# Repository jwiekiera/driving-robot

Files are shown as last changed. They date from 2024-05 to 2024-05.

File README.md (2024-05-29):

# Driving Robot

Project description: The project aims to create a mobile robot. The device can overcome obstacles detected by sensors (e.g., walls, objects on the ground). The robot moves using mechanical wheels.

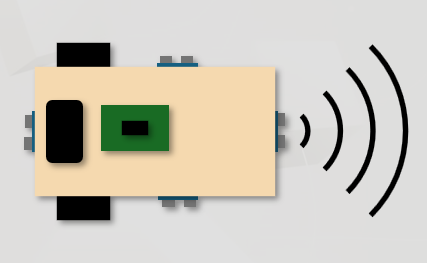
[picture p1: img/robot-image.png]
Robot image


* (20.10.2023) **Version 0.1**: Project work initiation
* (20.12.2023) **Version 0.2:** Placement of components on the platform
* (27.12.2023) **Version 0.3:** Completion of project implementation on the breadboard
* (09.02.2024) **Version 0.4:** Soldering the components together
* (13.02.2024) **Version 1.0:** Final version of the project

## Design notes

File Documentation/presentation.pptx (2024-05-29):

## Robot jeżdżący

Joanna Wiekiera

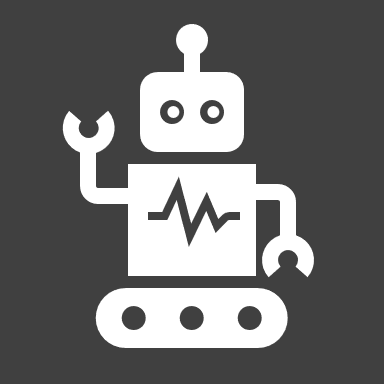
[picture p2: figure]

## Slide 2

Założenia

Robot jeżdżący, potrafiący omijać napotkane przeszkody

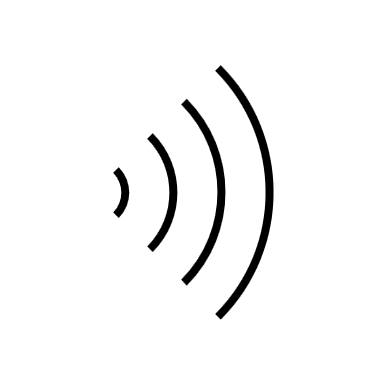
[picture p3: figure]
Wi-Fi outline

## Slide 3

Założenia

Robot jeżdżący, potrafiący omijać napotkane przeszkody

!

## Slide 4

Założenia

Robot jeżdżący, potrafiący omijać napotkane przeszkody

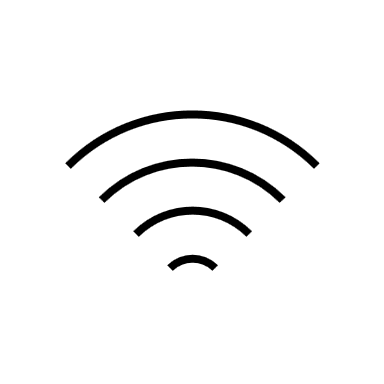
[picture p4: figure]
Wi-Fi outline

?

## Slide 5

Założenia

Robot jeżdżący, potrafiący omijać napotkane przeszkody

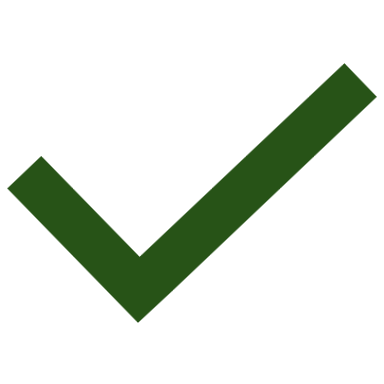
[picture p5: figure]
Checkmark with solid fill

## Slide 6

Założenia

Robot jeżdżący, potrafiący omijać napotkane przeszkody

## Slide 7

Założenia

Plany na rozwój: zaimplementowanie algorytmu parkowania równoległego

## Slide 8

Założenia

Plany na rozwój: zaimplementowanie algorytmu parkowania równoległego

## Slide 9

Założenia

Plany na rozwój: zaimplementowanie algorytmu parkowania równoległego

?

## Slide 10

Założenia

Plany na rozwój: zaimplementowanie algorytmu parkowania równoległego

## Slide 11

Założenia

Plany na rozwój: zaimplementowanie algorytmu parkowania równoległego

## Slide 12

Założenia

Plany na rozwój: zaimplementowanie algorytmu parkowania równoległego

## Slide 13

Założenia

Plany na rozwój: zaimplementowanie algorytmu parkowania równoległego

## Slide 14

Założenia

Plany na rozwój: zaimplementowanie algorytmu parkowania równoległego

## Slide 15

Elementy

- moduł Arduino Uno Rev3 z mikrokontrolerem AVR ATmega328
- cztery czujniki ultradźwiękowe HC-SR04
- robot wyposażony w trzy kółka – dwa tylnie wyposażone w silniki i przednie nienapędzane
- sterowanie tylnymi kołami kontrolowane dwukanałowym sterownikiem silników L293D

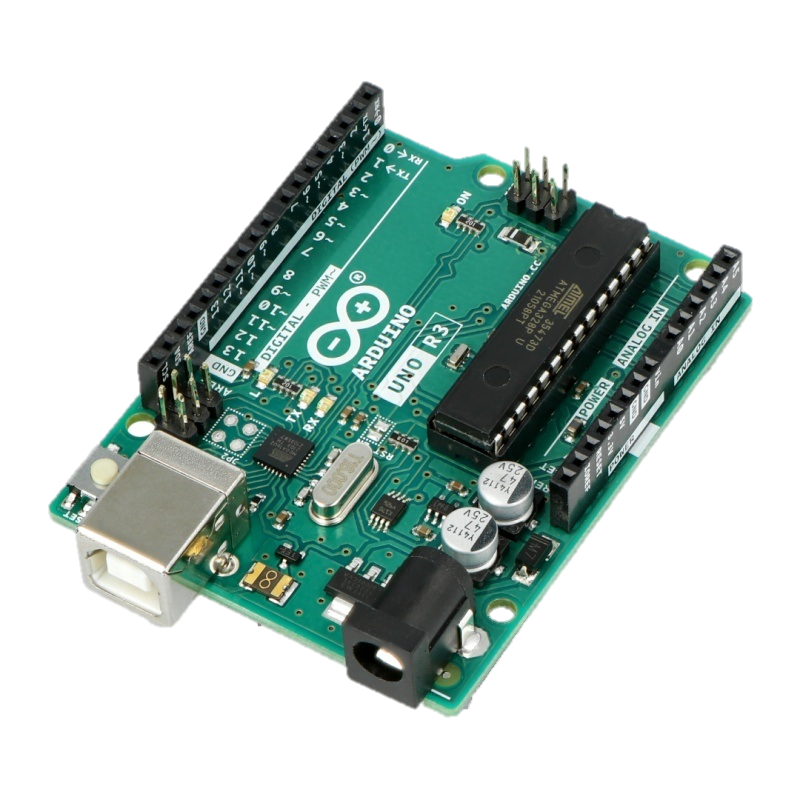
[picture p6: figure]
Arduino Uno Rev3 - A000066 Sklep Botland
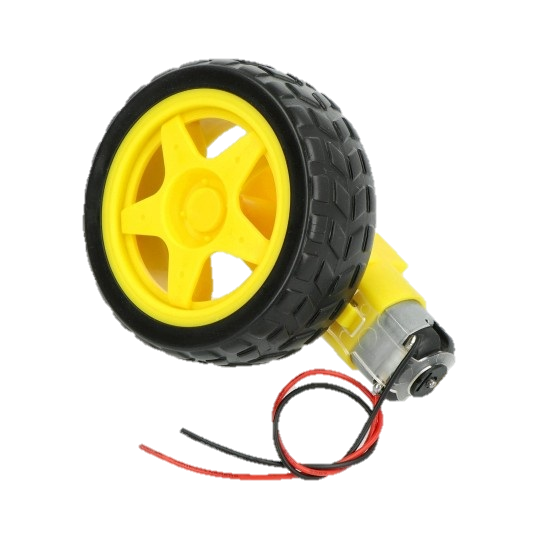
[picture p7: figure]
Koło + silnik 65x26mm 5V z przekładnią 48:1 + przewody
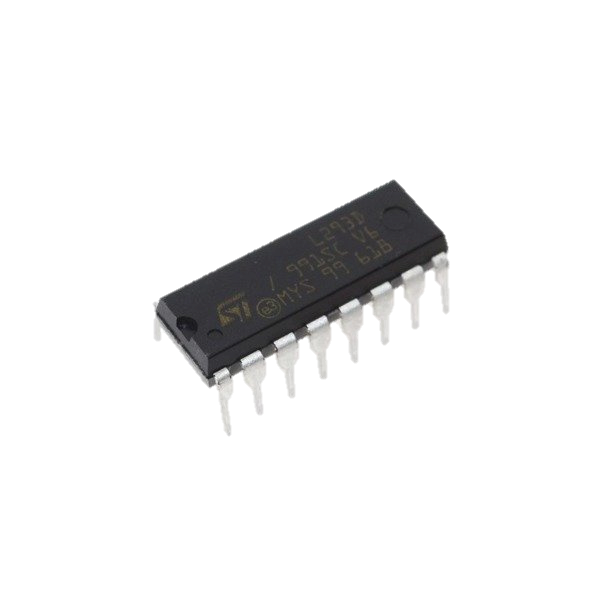
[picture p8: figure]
Układ scalony L293D - Sterownik silnika 2x Mostek H - DIP-16 L293
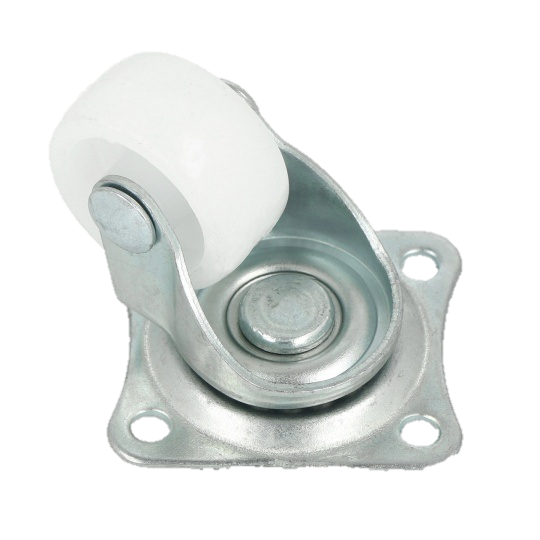
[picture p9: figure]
Obrotowe kółko do podwozia robota

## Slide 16

HC-SR04

Czujnik wysyła sygnał ultradźwiękowy, a następnie czeka na jego powrót po odbiciu od przeszkody. Odległość obliczana jest ze wzoru:

L=T∙340/2

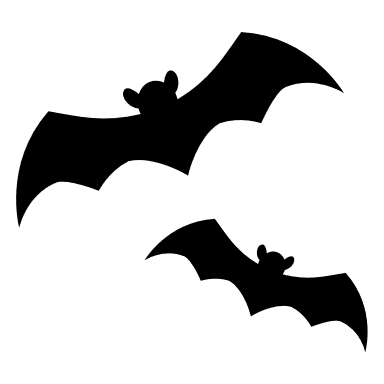
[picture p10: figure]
Bats with solid fill
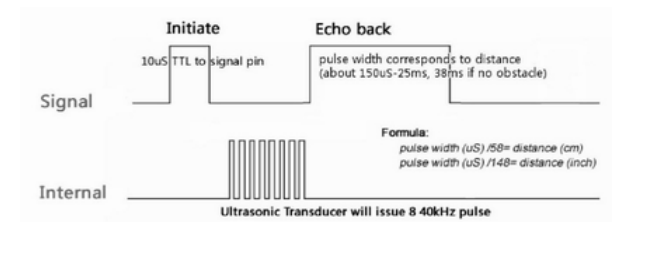
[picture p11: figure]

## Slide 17

HC-SR04

Czujnik wysyła sygnał ultradźwiękowy, a następnie czeka na jego powrót po odbiciu od przeszkody. Odległość obliczana jest ze wzoru:

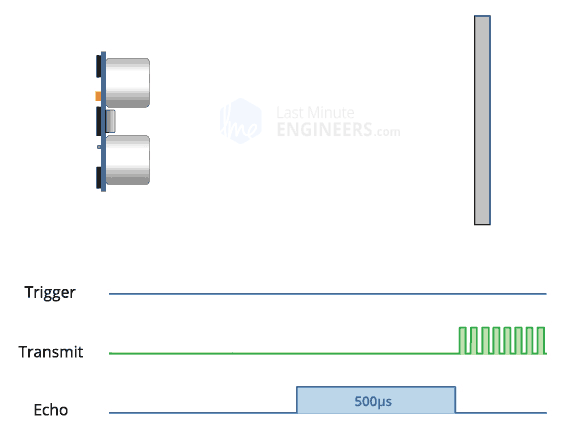
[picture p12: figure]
How HC-SR04 Ultrasonic Sensor Works & How to Interface It With Arduino

L=T∙340/2

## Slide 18

HC-SR04

L [m] – odległość
T [s] – czas od wysłania sygnału do jego powrotu
340 m/s – prędkość dźwięku w powietrzu
2 – uwzględnienie czasu w tylko w jedną stronę

Czujnik wysyła sygnał ultradźwiękowy, a następnie czeka na jego powrót po odbiciu od przeszkody. Odległość obliczana jest ze wzoru:

L=T∙340/2

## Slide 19

HC-SR04

L [cm] – odległość
T [μs] – czas od wysłania sygnału do jego powrotu

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

L=T /58

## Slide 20

L293D

Dwukanałowy sterownik silników DC (mostek H), sterujący kierunkiem kręcenia się kół poprzez zmianę biegunów zasilania

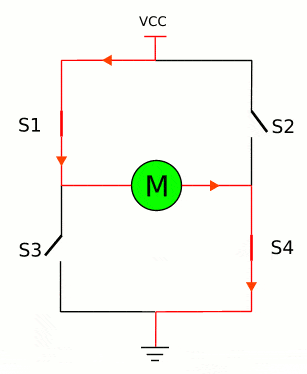
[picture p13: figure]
Teoria] Mostek H (H-bridge) - kompendium dla robotyka - Artykuły użytkowników - FORBOT

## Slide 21

L293D

Dwukanałowy sterownik silników DC (mostek H), sterujący kierunkiem kręcenia się kół poprzez zmianę biegunów zasilania

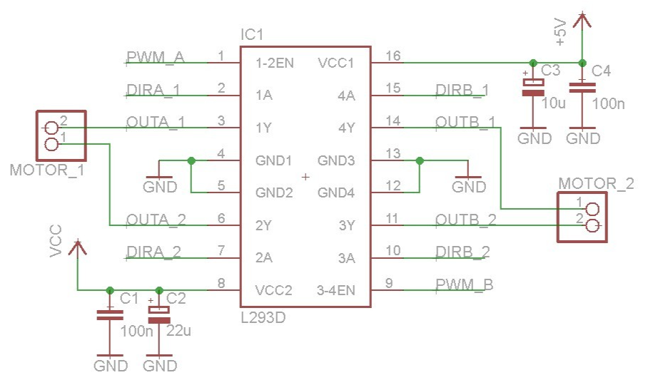
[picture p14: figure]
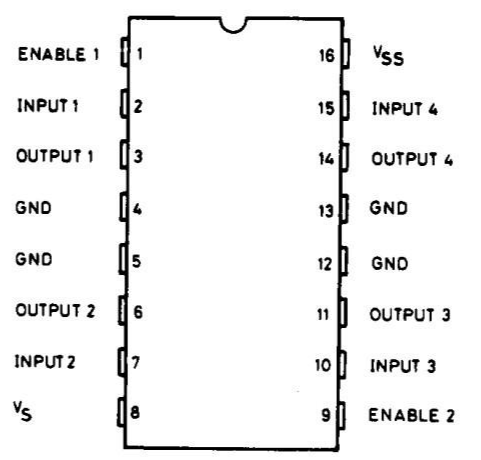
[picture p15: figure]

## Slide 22

Zasilanie

Zasilanie sześcioma bateriami AA (1,5V) połączonych szeregowo (co daje 9V).

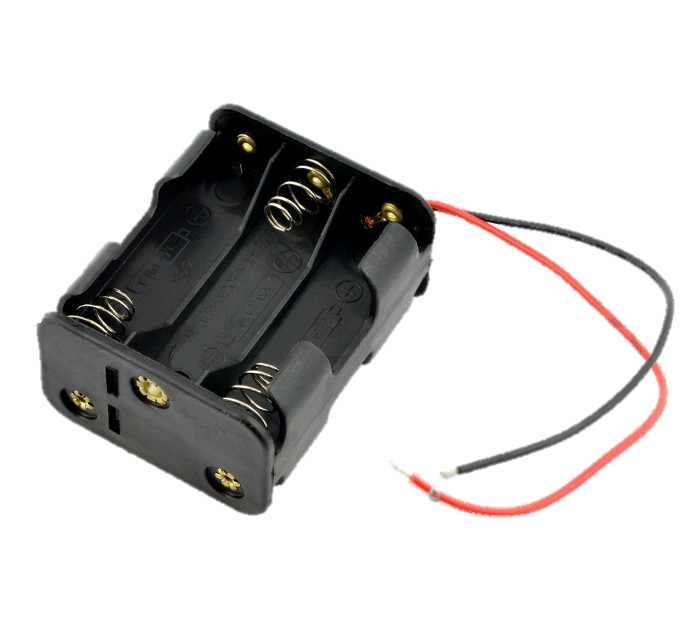
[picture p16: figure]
Slide
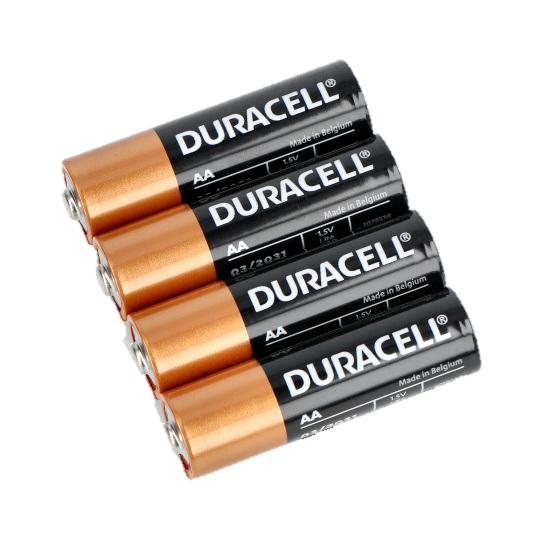
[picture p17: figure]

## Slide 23

Schemat
blokowy

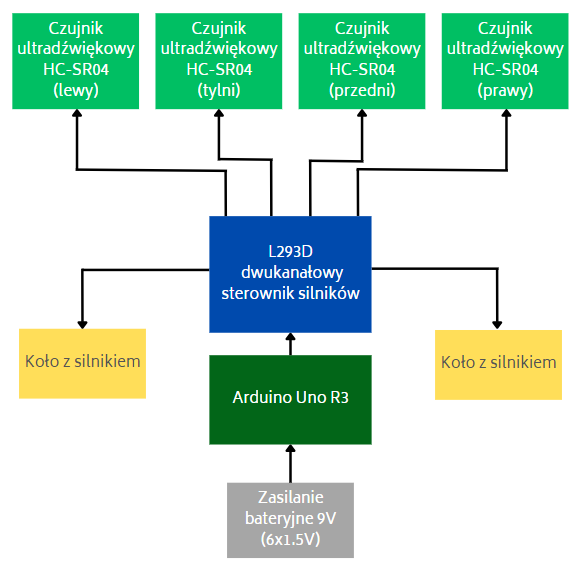
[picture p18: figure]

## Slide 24

Schemat
ideowy

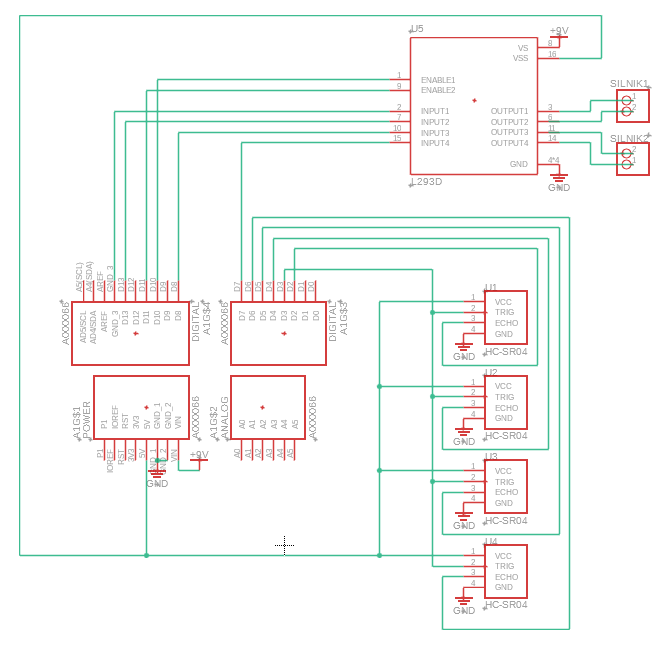
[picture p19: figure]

## Dziękuję za uwagę

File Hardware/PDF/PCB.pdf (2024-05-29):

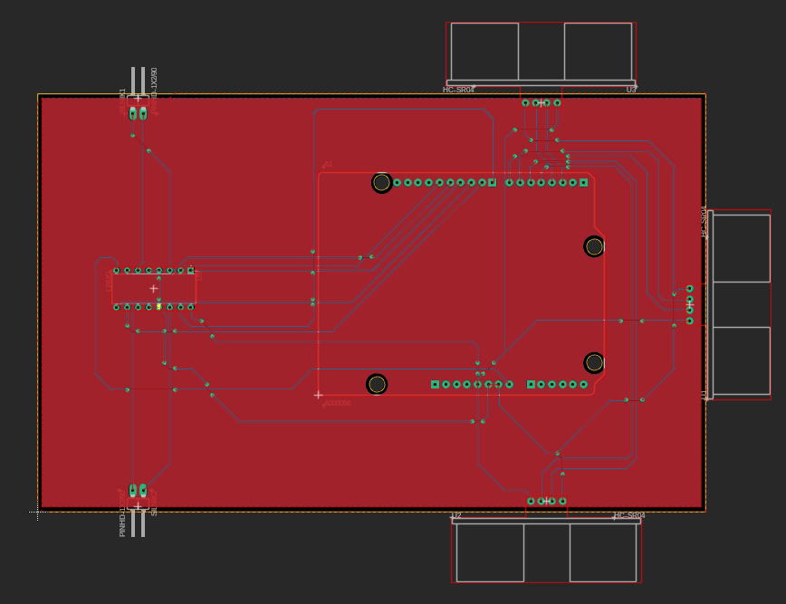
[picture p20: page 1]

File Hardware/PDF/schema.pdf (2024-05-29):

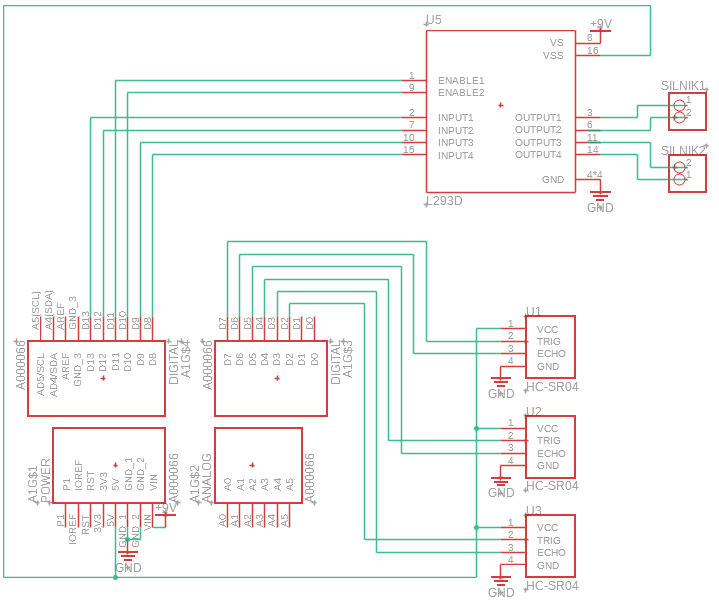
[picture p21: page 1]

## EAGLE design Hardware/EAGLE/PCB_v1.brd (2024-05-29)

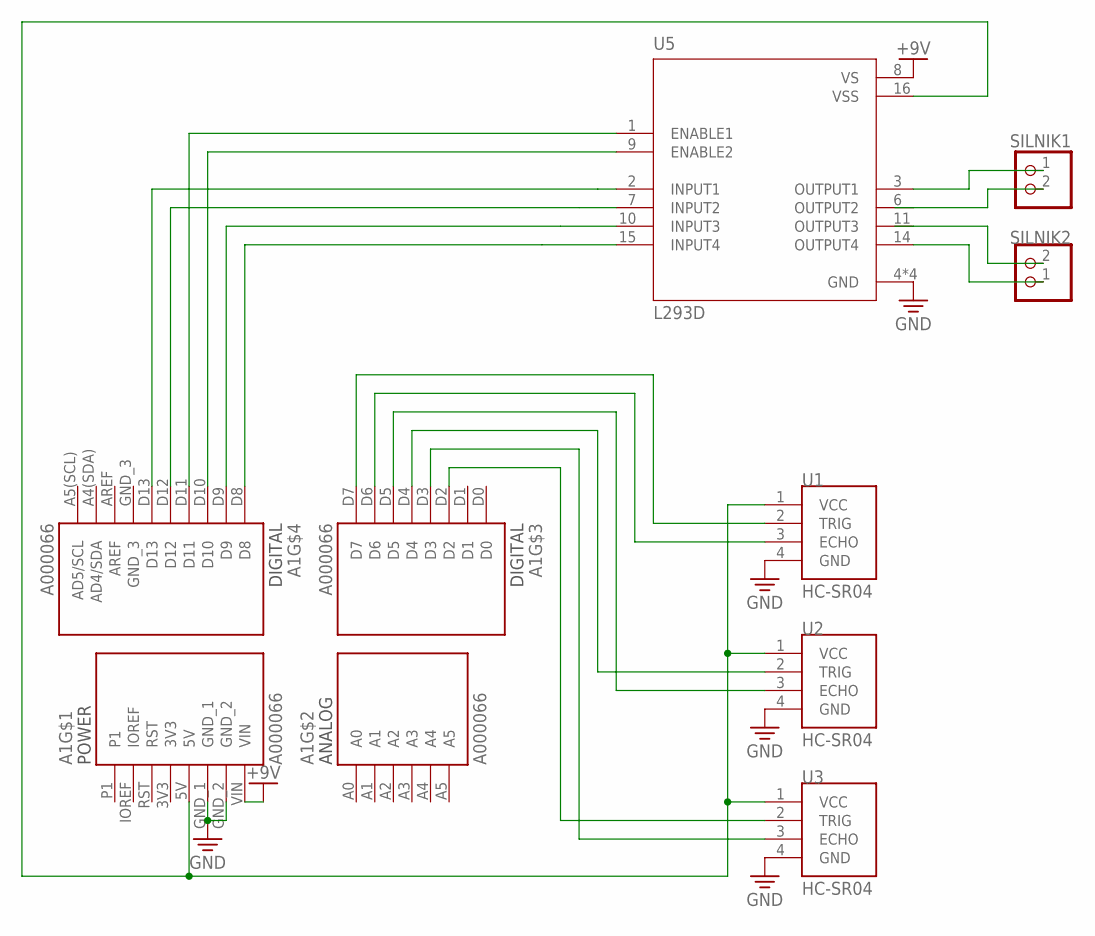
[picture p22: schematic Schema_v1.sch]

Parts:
A1: A000066; ARDUINO_A000066
SILNIK1, SILNIK2: PINHD-1X2/90; 1X02/90
U1, U2, U3: HC-SR04; XCVR_HC-SR04
U5: L293D; DIP880W50P254L2000H510Q16

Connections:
3V3: A1.3V3
+9V: A1.VIN, U5.8 (VS)
GND: A1.GND_1, A1.GND_2, U1.4 (GND), U2.4 (GND), U3.4 (GND), U5.4 (GND), U5.5 (GND), U5.12 (GND), U5.13 (GND)
GND_3: A1.GND_3
unnamed: A1.D2, U3.2 (TRIG)
unnamed: SILNIK1.1, U5.3 (OUTPUT1)
unnamed: SILNIK1.2, U5.6 (OUTPUT2)
unnamed: A1.D8, U5.15 (INPUT4)
unnamed: SILNIK2.2, U5.11 (OUTPUT3)
unnamed: SILNIK2.1, U5.14 (OUTPUT4)
unnamed: A1.D11, U5.1 (ENABLE1)
unnamed: A1.5V, U1.1 (VCC), U2.1 (VCC), U3.1 (VCC), U5.16 (VSS)
unnamed: A1.D9, U5.10 (INPUT3)
unnamed: A1.D12, U5.7 (INPUT2)
unnamed: A1.D10, U5.9 (ENABLE2)
unnamed: A1.D13, U5.2 (INPUT1)
unnamed: A1.D4, U2.2 (TRIG)
unnamed: A1.D5, U2.3 (ECHO)
unnamed: A1.D3, U3.3 (ECHO)
unnamed: A1.D6, U1.3 (ECHO)
unnamed: A1.D7, U1.2 (TRIG)

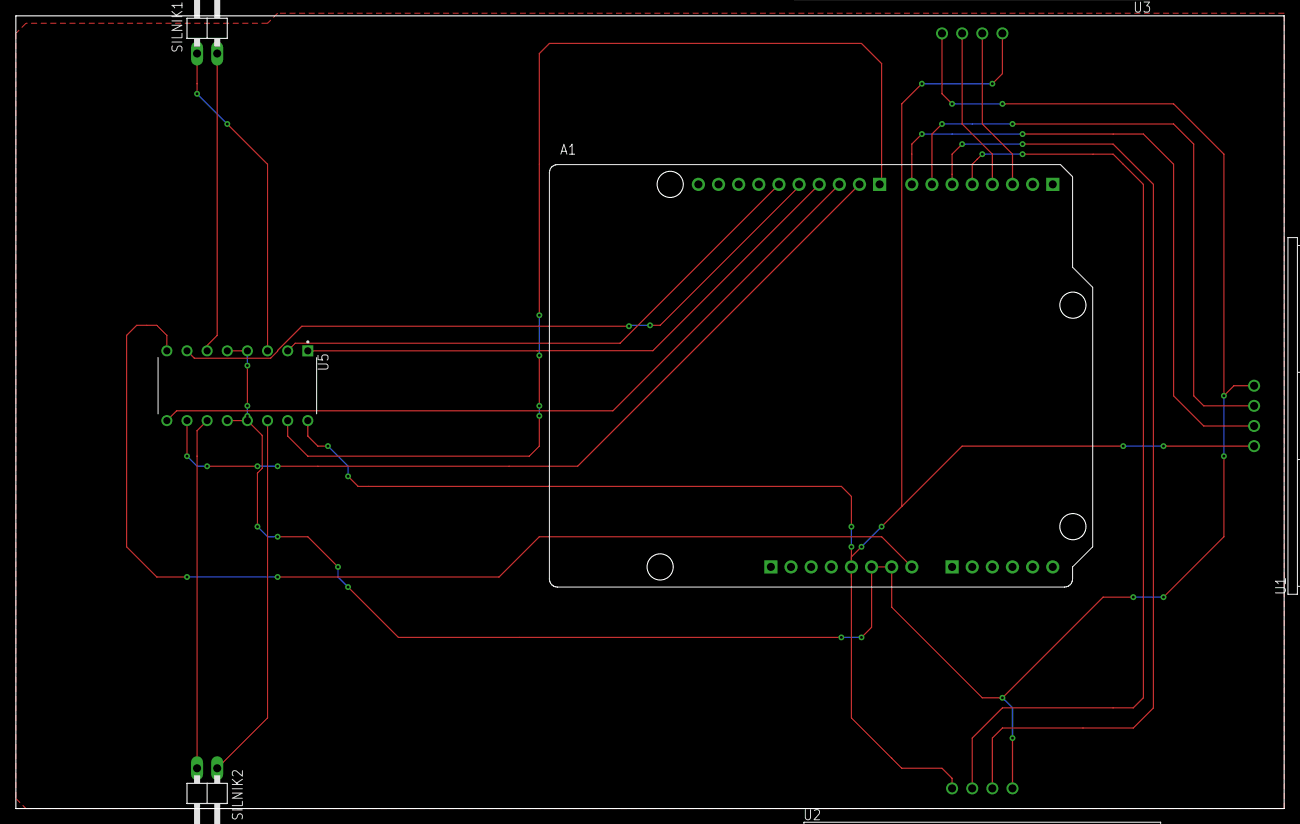
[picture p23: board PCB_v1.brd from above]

Board: 2 copper layers, 160.0 x 100.0 mm, 7 parts (0 on the bottom side), 19 nets.

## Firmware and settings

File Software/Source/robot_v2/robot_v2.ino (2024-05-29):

#define inputRight1 12 //pierwszy pin determinujacy kierunek prawego koła (HIGH - do przodu)
#define inputRight2 13 //pierwszy pin determinujacy kierunek prawego koła (HIGH - do tyłu)
#define enablePinRight 11 // PWM prawego koła (nadawanie prędkości obrotowej prawego koła)

#define inputLeft1 8 //pierwszy pin determinujacy kierunek lewego koła (HIGH - do przodu)
#define inputLeft2 9 //pierwszy pin determinujacy kierunek lewego koła (HIGH - do tyłu)
#define enablePinLeft 10 // PWM lewego koła (nadawanie prędkości obrotowej lewego koła)

#define trigPinFront 7 //wyjście odpowiadające wejściu zezwalającemu przedmiego czujnika
#define echoPinFront 6 //wejście odpowiadające wyjściu przedniego czujnika zwracającego pomiar

#define trigPinRight 4 //wyjście odpowiadające wejściu zezwalającemu prawego czujnika
#define echoPinRight 5 //wejście odpowiadające wyjściu prawego czujnika zwracającego pomiar

#define trigPinLeft 2 //wyjście odpowiadające wejściu zezwalającemu lewego czujnika
#define echoPinLeft 3 //wejście odpowiadające wyjściu lewego czujnika zwracającego pomiar

#define barier 30.0 //odległość wyrażona w centymetrach, w przypadku której robot ma zatrzymać się przed dalszą jazdą 

#define degree90time 1200 //czas w mikrosekundach, przez jaki ma wykonywać się operacja skrętu, by robot skręcił o 90 stopni (na testowym podłożu)

#define motorSpeed 100 //częstotliwość decydująca o prędkości obrotowej silników

void setup() {
  Serial.begin (9600);

  pinMode(inputRight1, OUTPUT); //ustawienie pierwszego pinu prawego koła na wyjście
  pinMode(inputRight2, OUTPUT); //ustawienie drugiego pinu prawego koła na wyjście
  pinMode(enablePinRight, OUTPUT); //ustawienie PWM prawego koła na wyjście (zakres 0-225)
  
  pinMode(inputLeft1, OUTPUT); //ustawienie pierwszego pinu lewego koła na wyjście
  pinMode(inputLeft2, OUTPUT); //ustawienie drugiego pinu lewego koła na wyjście
  pinMode(enablePinLeft, OUTPUT); //ustawienie PWM lewego koła na wyjście (zakres 0-225)

  pinMode(trigPinFront, OUTPUT); // ustawienie pinów podłączonych do trig czujnika jako wyjście
  pinMode(echoPinFront, INPUT); // ustawienie pinów podłączonych do echo czujnika jako wejście

  pinMode(trigPinRight, OUTPUT);
  pinMode(echoPinRight, INPUT);

  pinMode(trigPinLeft, OUTPUT);
  pinMode(echoPinLeft, INPUT);

  analogWrite(enablePinRight, motorSpeed); //nadanie prędkości obrotowej silników
  analogWrite(enablePinLeft, motorSpeed); 
}

void loop() {
  // algorytm omijania napotkanej przeszkody 
  if(measureDistance('f') > barier){
    goForward();
    delay(100);
  }
  else{
    stop(1000);
    if(measureDistance('r') > barier){
      turnRight(degree90time);
    } else if(measureDistance('l') > barier) {
      turnLeft(degree90time);
    } else{
        goBack(1000);
        if(measureDistance('r') > barier){
          turnRight(degree90time);
        } else if(measureDistance('l') > barier) {
          turnLeft(degree90time);
        }
    }
  }
}

// pomiar odległości na wybranym czujniku
// parametr: direction - wybór kierunku pomiaru:
//f - front, przedmi czujnik
//r - right, prawy czujnik
//l - left, lewy czujnik
float measureDistance(char direction) {
  float czas, dystans;
  if(direction == 'f'){
    digitalWrite(trigPinFront, HIGH); // nadanie sygnału czujnika, rozpoczęcie pomiaru odkległości
    delayMicroseconds(10); // odczekanie 10 mikrosekund
    digitalWrite(trigPinFront, LOW);
 
    czas = pulseIn(echoPinFront, HIGH); // odczyt czasu pomiaru 
  }
  else if(direction == 'r'){
    digitalWrite(trigPinRight, HIGH);
    delayMicroseconds(10);
    digitalWrite(trigPinRight, LOW);
 
    czas = pulseIn(echoPinRight, HIGH);

  }
  else if(direction == 'l'){
    digitalWrite(trigPinLeft, HIGH);
    delayMicroseconds(10);
    digitalWrite(trigPinLeft, LOW);
 
    czas = pulseIn(echoPinLeft, HIGH);
  }

  dystans = czas / 58.00; // obliczenie odległości od przeszkody (w centymetrach)
  // testowe wypisanie odkległości
  Serial.print(direction);
  Serial.print(": ");
  Serial.println(dystans);

  return dystans;
}

// skręt w prawo 
// parametr: time - czas skrętu
void turnRight(long time){
  rightRun(1);
  leftRun(0);
  delay(time);
}

// skręt w lewo 
// parametr: time - czas skrętu
void turnLeft(long time){
  rightRun(0);
  leftRun(1);
  delay(time);
}

// jazda do przodu
// parametr: time - czas jazdy
void goForward(){
  rightRun(1);
  leftRun(1);  
}

// jazda do tyłu
// parametr: time - czas jazdy
void goBack(long time){
  rightRun(-1);
  leftRun(-1); 
  delay(time);
}

// zatrzymanie się robota
// parametr: time - czas zatrzymania
void stop(int time){
  rightRun(0);
  leftRun(0);
  delay(time);
}

// nadanie kierunku prawego koła
// parametr: i - kierunek jazdy:
// -1 - koło jedzie do tyłu
//  0 - koło się zatrzymuje
//  1 - koło jedzie do przodu
void rightRun(int i){
  if(i == -1) { //back
    digitalWrite(inputRight1, LOW);
    digitalWrite(inputRight2, HIGH);
  }
  else if(i == 0){ //stop
    digitalWrite(inputRight1, LOW);
    digitalWrite(inputRight2, LOW);
  }
  else if(i == 1){ //forward
    digitalWrite(inputRight1, HIGH);
    digitalWrite(inputRight2, LOW);
  }
}

// nadanie kierunku lewego koła
// parametr: i - kierunek jazdy:
// -1 - koło jedzie do tyłu
//  0 - koło się zatrzymuje
//  1 - koło jedzie do przodu
void leftRun(int i){
  if(i == -1) { //back
    digitalWrite(inputLeft1, LOW);
    digitalWrite(inputLeft2, HIGH);
  }
  else if(i == 0){ //stop
    digitalWrite(inputLeft1, LOW);
    digitalWrite(inputLeft2, LOW);
  }
  else if(i == 1){ //forward
    digitalWrite(inputLeft1, HIGH);
    digitalWrite(inputLeft2, LOW);
  }
}

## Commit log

2024-05-29 Adding documentation, software and hardware
    [Płytka_PCB_v1.brd, Schemat_v1.sch]
2024-05-29 Renaming files names
    [PCB_v1.brd, Schema_v1.sch]
